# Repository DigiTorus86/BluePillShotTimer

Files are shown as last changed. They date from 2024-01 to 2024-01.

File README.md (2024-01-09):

# Blue Pill Shot Timer

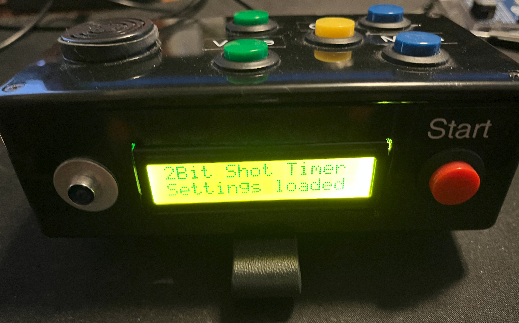
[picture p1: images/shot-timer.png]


The Blue Pill Shot Timer is a portable device for measuring the times between a start signal and a loud noise (typically a round going off in firearms training).  It also measures time intervals between successive shots in strings of fire.

Most settings can be customized and are saved to the STM32F103 EEPROM.

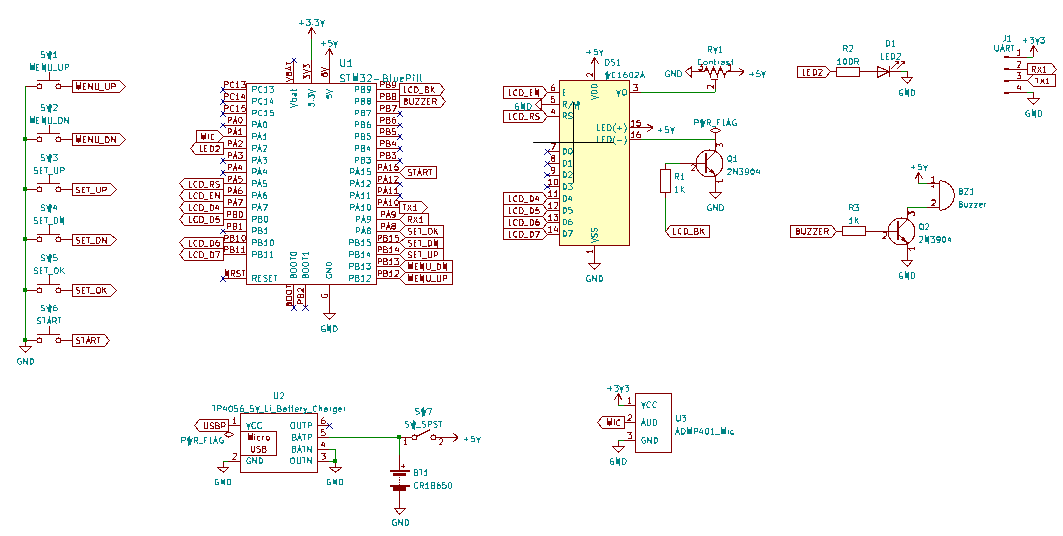
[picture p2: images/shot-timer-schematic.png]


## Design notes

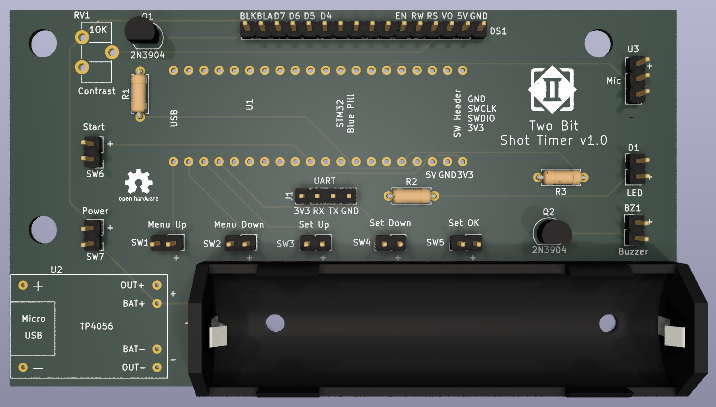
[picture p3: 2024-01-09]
images/shot-timer-pcb.png

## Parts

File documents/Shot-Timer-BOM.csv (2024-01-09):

Item | Qty | Reference(s) | Value | LibPart | Footprint | Datasheet | DNP
1 | 1 | BT1 | CR18650 | Device:Battery | Battery:BatteryHolder_MPD_BH-18650-PC2 | ~
2 | 1 | BZ1 | Buzzer | Device:Buzzer | Connector_PinHeader_2.54mm:PinHeader_1x02_P2.54mm_Vertical | ~
3 | 1 | D1 | LED2 | Device:LED | Connector_PinHeader_2.54mm:PinHeader_1x02_P2.54mm_Vertical | ~
4 | 1 | DS1 | WC1602A | Display_Character:WC1602A | Connector_PinHeader_2.54mm:PinHeader_1x16_P2.54mm_Vertical | http://www.wincomlcd.com/pdf/WC1602A-SFYLYHTC06.pdf
5 | 1 | J1 | UART | Connector:Conn_01x04_Male | Connector_PinHeader_2.54mm:PinHeader_1x04_P2.54mm_Vertical | ~
6 | 2 | Q1, Q2 | 2N3904 | Transistor_BJT:2N3904 | Package_TO_SOT_THT:TO-92_Inline | https://www.onsemi.com/pub/Collateral/2N3903-D.PDF
7 | 2 | R1, R3 | 1K | Device:R | Resistor_THT:R_Axial_DIN0207_L6.3mm_D2.5mm_P7.62mm_Horizontal | ~
8 | 1 | R2 | 100R | Device:R | Resistor_THT:R_Axial_DIN0207_L6.3mm_D2.5mm_P7.62mm_Horizontal | ~
9 | 1 | RV1 | Contrast | Device:R_Potentiometer_Trim_US | Potentiometer_THT:Potentiometer_ACP_CA9-H5_Horizontal | ~
10 | 1 | SW1 | MENU_UP | Switch:SW_Push | Connector_PinHeader_2.54mm:PinHeader_1x02_P2.54mm_Vertical | ~
11 | 1 | SW2 | MENU_DN | Switch:SW_Push | Connector_PinHeader_2.54mm:PinHeader_1x02_P2.54mm_Vertical | ~
12 | 1 | SW3 | SET_UP | Switch:SW_Push | Connector_PinHeader_2.54mm:PinHeader_1x02_P2.54mm_Vertical | ~
13 | 1 | SW4 | SET_DN | Switch:SW_Push | Connector_PinHeader_2.54mm:PinHeader_1x02_P2.54mm_Vertical | ~
14 | 1 | SW5 | SET_OK | Switch:SW_Push | Connector_PinHeader_2.54mm:PinHeader_1x02_P2.54mm_Vertical | ~
15 | 1 | SW6 | START | Switch:SW_Push | Connector_PinHeader_2.54mm:PinHeader_1x02_P2.54mm_Vertical | ~
16 | 1 | SW7 | SW_SPST | Switch:SW_SPST | Connector_PinHeader_2.54mm:PinHeader_1x02_P2.54mm_Vertical | ~
17 | 1 | U1 | STM32-BluePill | TwoBitSymbols:STM32-BluePill | TwoBitFootprints:STM32_BluePill | https://www.electronicshub.org/getting-started-with-stm32f103c8t6-blue-pill/
18 | 1 | U2 | TP4056_5V_Li_Battery_Charger | tp4056_5v_li_battery_charger:TP4056_5V_Li_Battery_Charger | TwoBitFootprints:TP4056_Li_Battery_Charger_Breakout
19 | 1 | U3 | ADMP401_Mic | TwoBitSymbols:ADMP401_Microphone_Breakout | Connector_PinHeader_2.54mm:PinHeader_1x03_P2.54mm_Vertical

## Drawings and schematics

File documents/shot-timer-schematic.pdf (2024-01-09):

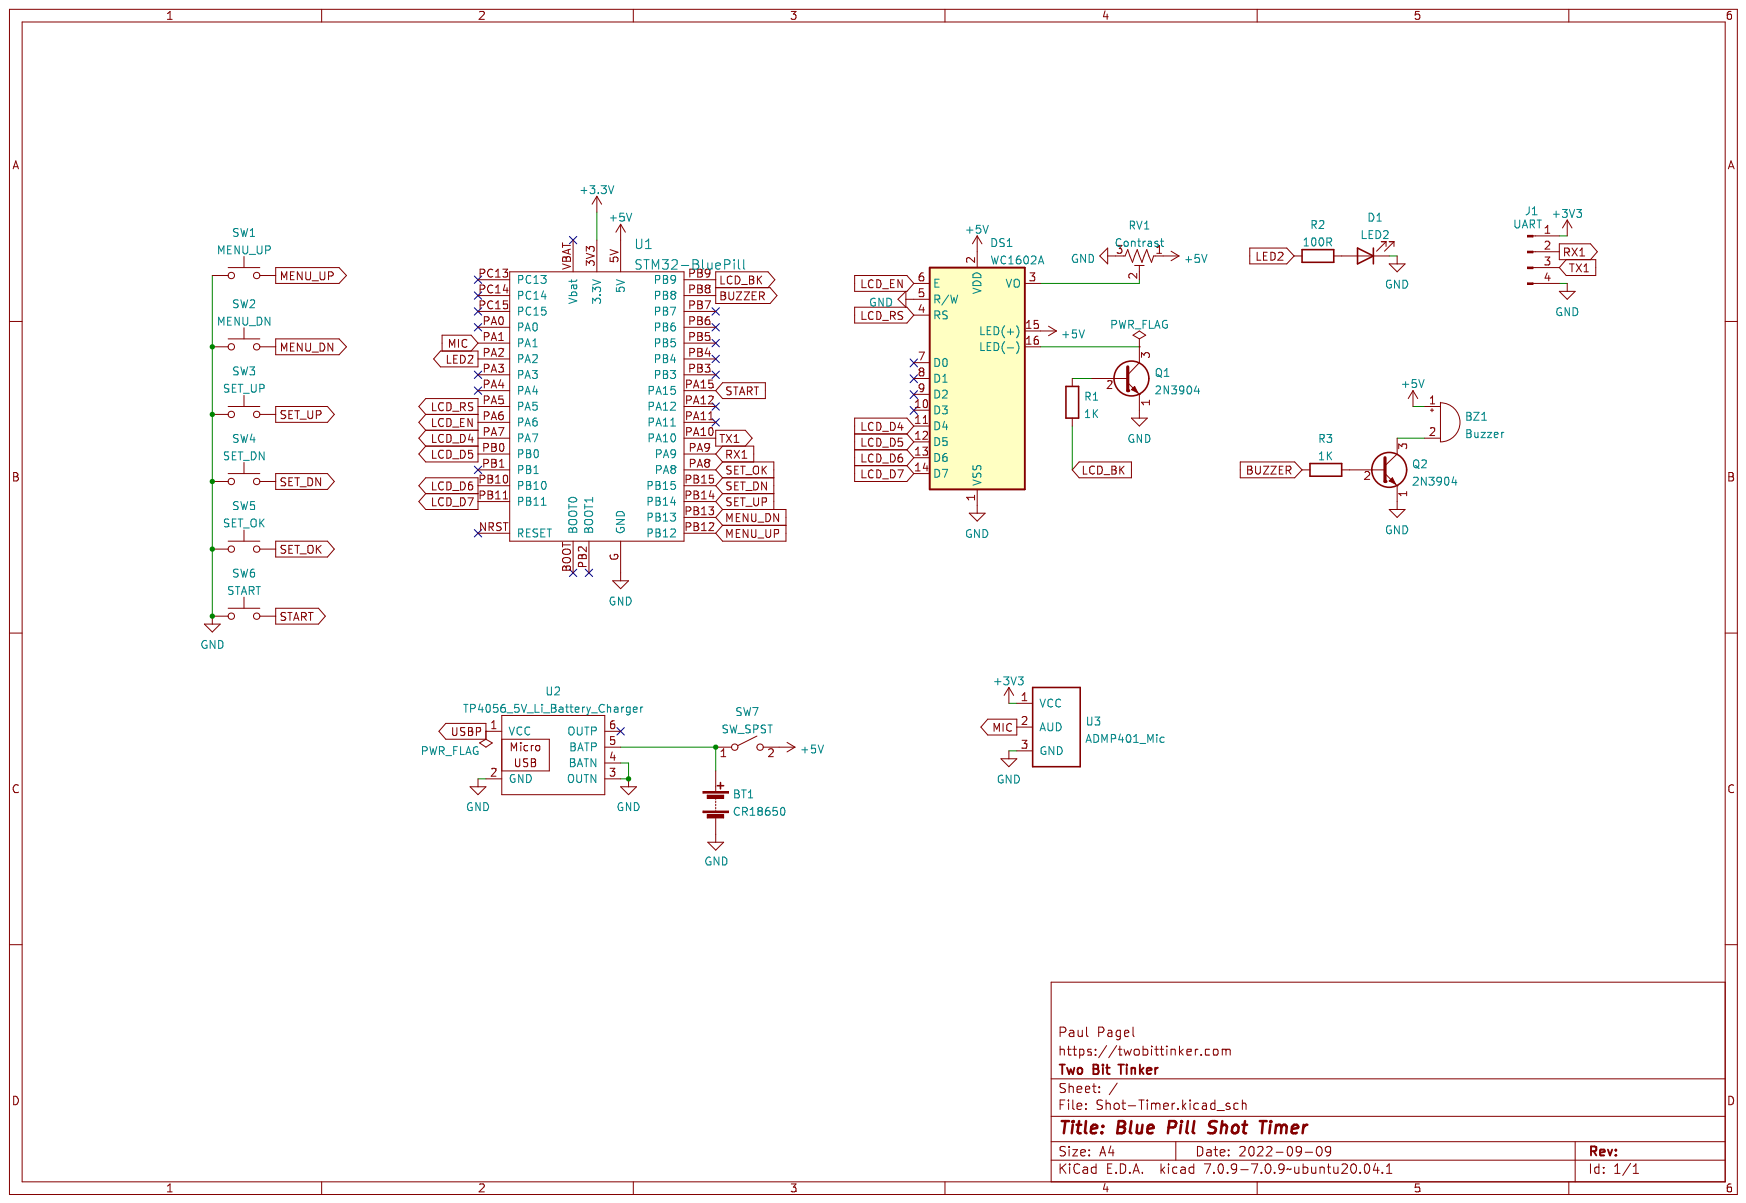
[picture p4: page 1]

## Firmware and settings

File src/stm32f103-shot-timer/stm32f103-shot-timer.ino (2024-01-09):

/* 2Bit Shot Timer
 *  
 * Configurable shot timer for detecting and recording shot times. 
 *  
 * Requires:
 * - STM32 BluePill (or similar microcontroller)
 * - 16x2 LCD character display
 * - ADMP401 Analog Microphone (or similar)
 * - Active Buzzer 3-24V
 * - 5 buttons
 * 
 * See BOM doc for full component list.
 * 
 * Uses the LiquidCrystal library for the HD44780-compatible LCD control:
 * https://github.com/arduino-libraries/LiquidCrystal
 * 
 * Uses the FlashStorage library by Khoi Hoang for storing user config settings in flash:
 * https://github.com/khoih-prog/FlashStorage_STM32F1
 *  
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
 * - 16x2 LCD Character Display Pins -
 * LCD 01 VSS pin to GND
 * LCD 02 VDD pin to 5V
 * LCD 03 VO pin to POT
 * LCD 04 RS pin to digital pin PB11
 * LCD 05 RW pin to GND
 * LCD 06 EN pin to digital pin PB10
 * LCD 07-10 D0 to D3 pins not used
 * LCD 11 D4 pin to digital pin PB0
 * LCD 12 D5 pin to digital pin PA7
 * LCD 13 D6 pin to digital pin PA6
 * LCD 14 D7 pin to digital pin PA5
 * LCD 15 BL+/BLA pin to 5V
 * LCD 16 BL-/BLK pin to GND
 */

#include <LiquidCrystal.h>
#include <FlashStorage_STM32F1.h>


#define FLASH_DEBUG                 2
#define USING_FLASH_SECTOR_NUMBER   (REGISTERED_NUMBER_FLASH_SECTORS - 2)

#define LCD_RS_PIN  PA5  //PB11
#define LCD_EN_PIN  PA6  //PB10
#define LCD_D4_PIN  PA7  //PB0
#define LCD_D5_PIN  PB0  //PA7
#define LCD_D6_PIN  PB10 //PA6
#define LCD_D7_PIN  PB11 //PA5
#define LCD_BK_PIN  PB9  // Backlight control connected to 2N3904 NPN base, connect BLK/- to emitter
#define MIC_PIN     PA1  // Analog in
#define BUZZER_PIN  PB8  // Buzzer control connected to 2N3904 NPN base, connect buzzer GND to emitter
#define MENU_UP_PIN PB12 // All button pins should be pulled up
#define MENU_DN_PIN PB13
#define SET_UP_PIN  PB14
#define SET_DN_PIN  PB15
#define SET_OK_PIN  PA8
#define START_PIN   PA15
#define LED1_PIN    PC13 // Built-in LED, in open-drain mode (LOW to turn on)
#define LED2_PIN    PA2  // Additional indicator LED

#define MAX_SHOTS   256
#define MAX_PARS    5
#define DC_OFFSET   2048   // DC offset in mic signal
#define NOISE       10     // Noise/hum/interference in mic signal

#define MIN_DETECT_THRESH 3000  // based on 12-bit ADC
#define MAX_DETECT_THRESH 4000

#define MIN_DEADTIME_SAMPLES 10
#define MAX_DEADTIME_SAMPLES 200


#define MIN_BUZZER_VOL 0        // PWM setting
#define MAX_BUZZER_VOL 250

#define MIN_BUZZER_MS 0
#define MAX_BUZZER_MS 1000

#define MIN_BKLIGHT_MS 0
#define MAX_BKLIGHT_MS 20000

#define EEPROM_VERSION 1
#define EEPROM_START   0xFEEDFACE
#define EEPROM_END     0xDEADBEEF

enum app_mode_type 
{
  MODE_TITLE,     // Display the app title
  MODE_MENU1,     // Start mode, delay times
  MODE_MENU2,     // Par times
  MODE_MENU3,     // Shot sensitivity
  MODE_MENU4,     // Buzzer volume and duration
  MODE_MENU5,     // Backlight duration + TBD
  MODE_STARTING,  // Countdown to start
  MODE_RECORDING, // Timer started, detecting and recording shots
  MODE_RESULTS,   // Display the recorded stats, split times
  MODE_REFRESH    // Set previous mode to refresh in order to trigger a redraw of the current screen
};

enum start_mode_type
{
  START_MODE_RANDOM,  // Use the a random delay between min and max value for the start countdown
  START_MODE_FIXED    // Use a specific countdown delay value (min_start_ms)
};

// ** Persisted configuration settings **

struct    app_config_type
{
  enum      start_mode_type start_mode; // Random or Fixed
  uint32_t  min_start_ms;
  uint32_t  max_start_ms; 
  uint16_t  par_count;
  long      par_ms[MAX_PARS];
  uint16_t  buzzer_vol;           // PWM setting for buzzer (0 = silent)
  uint32_t  buzzer_ms;            // Duration of buzzer sound
  uint32_t  bklight_ms;           // Backlight duration from when button last pushed to turnoff time
  int       detect_thresh;        // Shot detection threshold (using 12 bit ADC)
  long      min_interval_samples; // Minimum # of samples below detection threshold before next shot
};
app_config_type app_config;

// ** Operational values **
enum      app_mode_type app_mode, prev_app_mode;
long      start_time;             // All "time" values in reference to system clock millis()
long      end_time;
long      delay_end_time;
long      buzzer_off_time;
long      bklight_off_time;
long      par_time;
uint8_t   shot_count;
long      shot_time[MAX_SHOTS];
bool      buzzer_start_on;
bool      buzzer_par_on;

int       mic_lvl     = 10;       // Current "dampened" audio level
int       mic_min_avg = 0;        // For dynamic adjustment of graph low & high
int       mic_max_avg = 2048;

bool      btn_menu_up_pressed, btn_menu_up_released;
bool      btn_menu_dn_pressed, btn_menu_dn_released;
bool      btn_set_up_pressed, btn_set_up_released;
bool      btn_set_dn_pressed, btn_set_dn_released;
bool      btn_set_ok_pressed, btn_set_ok_released;
bool      btn_start_pressed, btn_start_released;


// The 16x2 LCD character display
LiquidCrystal lcd(LCD_RS_PIN, LCD_EN_PIN, LCD_D4_PIN, LCD_D5_PIN, LCD_D6_PIN, LCD_D7_PIN);

/*
 * Debug output for hex values
 */
void displayHex(uint16_t value)
{
  if (value <= 0xF)
    Serial.print("000");
  else if (value <= 0xFF)
    Serial.print("00");
  else if (value <= 0xFFF)
    Serial.print("0");
  Serial.print(value, HEX);
}

/*
 * Debug output for flash simulated EEPROM settings
 */
void displayEEPROM()
{
  uint8_t data;

  Serial.println("----Simulated EEPROM Dump----");
  lcd.clear();
  lcd.print("Dump:");
  
  for (int i = 0; i < 128; i++)
  {
    data = EEPROM.read(i);
    displayHex(data);
    Serial.print(" ");
    lcd.print(" ");
    lcd.print(data, HEX);

    if (i % 16 == 0)
    {
      delay(1000);
    }
    
  }
  Serial.println("");
  Serial.println("--------");
}

/*
 * Reads the app config settings from flash memory/simulated EEPROM if they are available.
 * Returns true if able to read settings.  False if no settings were read or failed validation.
 */
bool readConfig()
{
  int address = 0x0;
  int data;
  int data_version;
  
  Serial.print(F("\nStart EmulatedEEPROM on ")); Serial.println(BOARD_NAME);
  Serial.println(FLASH_STORAGE_STM32F1_VERSION);
  
  EEPROM.init();
     
  EEPROM.get(address, data);
  if (data != EEPROM_START)
  {
    Serial.print("Initial read value: ");
    displayHex(data);
    Serial.println();
    Serial.println(F("Unable to load settings from flash."));
    
    return false;
  }

  Serial.println(F("Getting settings from Simulated EEPROM"));

  // Future-proofing in case multiple firmware eeprom versions 
  address += sizeof(EEPROM_START);
  EEPROM.get(address, data_version);
  Serial.print(F("Data version: "));
  Serial.println(data_version);

  // -- read the actual config settings -- //

  address += sizeof(data_version);
  EEPROM.get(address, app_config);
  
  Serial.print(F("Start Mode: "));
  Serial.println(app_config.start_mode);
  Serial.print(F("Min Delay: "));
  Serial.println(app_config.min_start_ms);
  Serial.print(F("Max Delay: "));
  Serial.println(app_config.max_start_ms);

  Serial.print(F("Par Times: "));
  for (int i = 0; i < MAX_PARS; i++)
  {
    Serial.print(app_config.par_ms[i]);
  }

  Serial.println("");
  Serial.print(F("Buzzer ms: "));
  Serial.println(app_config.buzzer_ms);
  Serial.print(F("Backlight ms: "));
  Serial.println(app_config.bklight_ms);

  address += sizeof(app_config);
  EEPROM.get(address, data);
  if (data != EEPROM_END)
  {
    Serial.println(F("EEPROM write validation failed!"));
    Serial.print(F("Validation read value: "));
    displayHex(data);
    Serial.println();
    
    return false;
  }

  return true;
}

/*
 * Writes the app config settings to flash memory/simulated EEPROM
 * Returns true on success, false on failure.
 */
bool writeConfig()
{
  int address = 0x0;
  int data;

  data = EEPROM_START;
  EEPROM.put(address, data);

  data = EEPROM_VERSION;
  address += sizeof(EEPROM_START);
  EEPROM.put(address, data);

  address += sizeof(data);
  EEPROM.put(address, app_config);

  data = EEPROM_END;
  address += sizeof(app_config);
  EEPROM.put(address, data);

  EEPROM.commit();

  data = 0;
  EEPROM.get(address, data);
  
  return (data == EEPROM_END);
}

/*
 * Setup and Initialization 
 */
void setup() 
{
  Serial.begin(115200);
  while (!Serial);
  Serial.println("2Bit Shot Timer");
  
  // LEDs and display
  pinMode(LED1_PIN, OUTPUT);
  pinMode(LED2_PIN, OUTPUT);
  ledsOn();
  
  pinMode(LCD_BK_PIN, OUTPUT);
  digitalWrite(LCD_BK_PIN, HIGH); // turn on backlight
  
  lcd.begin(16, 2);
  lcd.setCursor(0, 0);
  lcd.print("2Bit Shot Timer");

  // Buttons 
  pinMode(MENU_UP_PIN, INPUT_PULLUP);
  pinMode(MENU_DN_PIN, INPUT_PULLUP);
  pinMode(SET_UP_PIN, INPUT_PULLUP);
  pinMode(SET_DN_PIN, INPUT_PULLUP);
  pinMode(SET_OK_PIN, INPUT_PULLUP);
  pinMode(START_PIN, INPUT_PULLUP);

  // Sound
  pinMode(MIC_PIN, INPUT_ANALOG);
  pinMode(BUZZER_PIN, OUTPUT);

  randomSeed(analogRead(MIC_PIN)); // for random start times

  if (readConfig())
  {
    lcd.setCursor(0, 1);
    lcd.print("Settings loaded");
  }
  else
  {
    // Unable to read from the simulated EEPROM or not previously set up
    // Use default configuration values instead

    lcd.setCursor(0, 1);
    lcd.print("Factory settings");
    
    app_config.start_mode = START_MODE_RANDOM;
    app_config.min_start_ms = 2000;
    app_config.max_start_ms = 5000;
    app_config.par_count = 1;

    for (int i = 0; i < MAX_PARS; i++)
    {
      app_config.par_ms[i] = 5000L;  
    }

    app_config.buzzer_vol = 75;
    app_config.buzzer_ms = 100;
    app_config.bklight_ms = 8000;
    app_config.detect_thresh = 3650;
    app_config.min_interval_samples = 50;

    if (!writeConfig())
    {
      lcd.setCursor(0, 1);
      lcd.print("EEPROM write err");
    }
  }
  
  bklight_off_time = millis() + app_config.bklight_ms;
  app_mode = MODE_TITLE;
  
  handleTitle();
  ledsOff();
}


void checkButtons()
{
  if (digitalRead(MENU_UP_PIN) == LOW)
  {
    btn_menu_up_pressed = true;
    bklight_off_time = millis() + app_config.bklight_ms;
  }
  else if(btn_menu_up_pressed)
  {
    btn_menu_up_pressed = false;
    btn_menu_up_released = true;
  }
  else
  {
    btn_menu_up_pressed = false;
    btn_menu_up_released = false;
  }

  if (digitalRead(MENU_DN_PIN) == LOW)
  {
    btn_menu_dn_pressed = true;
    bklight_off_time = millis() + app_config.bklight_ms;
  }
  else if(btn_menu_dn_pressed)
  {
    btn_menu_dn_pressed = false;
    btn_menu_dn_released = true;
  }
  else
  {
    btn_menu_dn_pressed = false;
    btn_menu_dn_released = false;
  }

  if (digitalRead(SET_UP_PIN) == LOW)
  {
    btn_set_up_pressed = true;
    bklight_off_time = millis() + app_config.bklight_ms;
  }
  else if(btn_set_up_pressed)
  {
    btn_set_up_pressed = false;
    btn_set_up_released = true;
  }
  else
  {
    btn_set_up_pressed = false;
    btn_set_up_released = false;
  }

  if (digitalRead(SET_DN_PIN) == LOW)
  {
    btn_set_dn_pressed = true;
    bklight_off_time = millis() + app_config.bklight_ms;
  }
  else if(btn_set_dn_pressed)
  {
    btn_set_dn_pressed = false;
    btn_set_dn_released = true;
  }
  else
  {
    btn_set_dn_pressed = false;
    btn_set_dn_released = false;
  }

  if (digitalRead(SET_OK_PIN) == LOW)
  {
    btn_set_ok_pressed = true;
    bklight_off_time = millis() + app_config.bklight_ms;
  }
  else if(btn_set_ok_pressed)
  {
    btn_set_ok_pressed = false;
    btn_set_ok_released = true;
  }
  else
  {
    btn_set_ok_pressed = false;
    btn_set_ok_released = false;
  }

  if (digitalRead(START_PIN) == LOW)
  {
    btn_start_pressed = true;
    bklight_off_time = millis() + app_config.bklight_ms;
  }
  else if(btn_start_pressed)
  {
    btn_start_pressed = false;
    btn_start_released = true;
  }
  else
  {
    btn_start_pressed = false;
    btn_start_released = false;
  }
}

/*
 * Turn all LEDs on
 */
void ledsOn()
{
  digitalWrite(LED1_PIN, LOW);
  digitalWrite(LED2_PIN, HIGH);
}

/*
 * Turn all LEDs off
 */
void ledsOff()
{
  digitalWrite(LED1_PIN, HIGH);
  digitalWrite(LED2_PIN, LOW);
}

/*
 * Turn the buzzer on
 */
void startBuzzer()
{
  ledsOn();
  
  pinMode(BUZZER_PIN, OUTPUT); // required when switching between digital and analog
  
  if (app_config.buzzer_vol == MAX_BUZZER_VOL)
  {
    digitalWrite(BUZZER_PIN, HIGH); // significantly louder than analog PWM
  }
  else
  {
    analogWrite(BUZZER_PIN, app_config.buzzer_vol);  
  }
  
  // digitalWrite(BUZZER_PIN, HIGH);
  digitalWrite(LCD_BK_PIN, LOW);
}

// Turn the buzzer off
void stopBuzzer()
{
  ledsOff();
  if (app_config.buzzer_vol == MAX_BUZZER_VOL)
  {
    digitalWrite(BUZZER_PIN, LOW);
  }
  else
  {
    analogWrite(BUZZER_PIN, 0);  
  }

  digitalWrite(LCD_BK_PIN, HIGH);
}


/*
 * Displays time to 2 decimal places, i.e. 9.87
 */
void printTime(long ms)
{
  char buff[10];
  float secs;

  secs = (float)ms / 1000.0f;
  sprintf(buff, "%d.%02d", (int)secs, (int)abs(secs*100)%100);
  lcd.print(buff);
}

/*
 * Displays time to 1 decimal place, i.e. 9.8
 */
void printSeconds(uint32_t ms)
{
  char buff[10];
  float secs;

  secs = (float)ms / 1000.0f;
  sprintf(buff, "%d.%01d", (int)secs, (int)abs(secs*10)%10);
  lcd.print(buff);
}

/*
 * Detects a gunshot or other loud noise that exceeds the analog detection threshold.
 */
void detectShot()
{
  static uint32_t samples_below_thresh;
  int             sample = 0;
  
  sample = analogRead(MIC_PIN);             // Raw reading from mic 
  sample = abs(sample - 2048 - DC_OFFSET);  // Center on zero
  sample = (sample <= NOISE) ? 0 : (sample - NOISE); // Remove noise/hum
  mic_lvl = ((mic_lvl * 7) + sample) >> 3;   // "Dampened" reading (else looks twitchy)

  lcd.setCursor(0,1);
  lcd.print(mic_lvl);
  lcd.print("  ");

  if ((mic_lvl > app_config.detect_thresh) && !buzzer_start_on && (samples_below_thresh > app_config.min_interval_samples))
  {
    shot_count += 1;
    shot_time[shot_count] = millis();
    end_time = millis();
    samples_below_thresh = 0;

    ledsOn();
    lcd.setCursor(7, 1);
    lcd.print(shot_count);
    ledsOff();
  }
  else
  {
    samples_below_thresh += 1;
  }
}

/*
 * Display the app title
 */
void handleTitle()
{
  if (prev_app_mode != MODE_TITLE)
  {
    prev_app_mode = MODE_TITLE;
    
    lcd.clear();
    lcd.setCursor(0, 0);
    lcd.print("2Bit Shot Timer");
  
    lcd.setCursor(0, 1);
    lcd.print("v1.0");
  }

  checkButtons();

  if (btn_menu_up_released)
  {
    app_mode = MODE_MENU1;
  }

  if (btn_menu_dn_released)
  {
    app_mode = MODE_MENU5;
  }

  if (btn_start_released)
  {
    app_mode = MODE_STARTING;
  }
}

/*
 * Menu1:  Start Mode (Delay, Fixed)  
 *         Min Delay
 *         Max Delay
 */
void handleMenu1()
{
  static uint8_t active_field;
  static uint8_t max_fields;
  
  if (prev_app_mode != MODE_MENU1)
  {
    prev_app_mode = MODE_MENU1;
    
    lcd.clear();
    lcd.setCursor(0, 0);
    lcd.print("Delay: ");
    if (app_config.start_mode == START_MODE_FIXED)
    {
      lcd.print("Fixed");
      
      lcd.setCursor(0, 1);
      lcd.print("Sec:");
      printSeconds(app_config.min_start_ms);
      
      max_fields = 2;
    }
    else
    {
      lcd.print("Random");
      
      lcd.setCursor(0, 1);
      lcd.print("Min:"); 
      printSeconds(app_config.min_start_ms);
      
      lcd.setCursor(8, 2);
      lcd.print("Max:");
      printSeconds(app_config.max_start_ms);
      
      max_fields = 3;
    }

    switch (active_field)
    {
      case 0: // start mode
        lcd.setCursor(7, 0);
        break;
      
      case 1: // min start delay ms
        lcd.setCursor(4, 1);
        break;

      case 2: // max start delay ms
        lcd.setCursor(12, 1);
        break;
    }

    lcd.cursor();
    lcd.blink();
  }

  checkButtons();

  if (btn_set_ok_released)
  {
    active_field = (active_field < max_fields - 1) ? active_field + 1 : 0;
    
    prev_app_mode = MODE_REFRESH;
    return;
  }

  if (btn_set_up_released)
  {
    switch (active_field)
    {
      case 0: // start mode
        app_config.start_mode = (start_mode_type)((app_config.start_mode + 1) % 2);
        break;
      
      case 1: // min start delay ms
        app_config.min_start_ms = (app_config.min_start_ms < 9900) ? app_config.min_start_ms + 100 : 9900;
        app_config.max_start_ms = (app_config.max_start_ms < app_config.min_start_ms) ? app_config.min_start_ms : app_config.max_start_ms;
        break;

      case 2: // max start delay ms
        app_config.max_start_ms = (app_config.max_start_ms < 9900) ? app_config.max_start_ms + 100 : 9900;
        break;
    }

    prev_app_mode = MODE_REFRESH;
    return;
  }

  if (btn_set_dn_released)
  {
    switch (active_field)
    {
      case 0: // start mode
        app_config.start_mode = (start_mode_type)((app_config.start_mode + 1) % 2);
        break;
      
      case 1: // min start delay ms
        app_config.min_start_ms = (app_config.min_start_ms > 100) ? app_config.min_start_ms - 100 : 100;
        break;

      case 2: // max start delay ms
        app_config.max_start_ms = (app_config.max_start_ms > 100) ? app_config.max_start_ms - 100 : 100;
        app_config.min_start_ms = (app_config.min_start_ms < app_config.max_start_ms) ? app_config.min_start_ms : app_config.max_start_ms;
        break;
    }
    
    prev_app_mode = MODE_REFRESH;
    return;
  }

  if (btn_menu_up_released)
  {
    app_mode = MODE_MENU2;
    return;
  }

  if (btn_menu_dn_released)
  {
    app_mode = MODE_RESULTS;
    writeConfig();
    return;
  }

  if (btn_start_released)
  {
    app_mode = MODE_STARTING;
  }
}

/*
 * Menu2: Par Times (count)
 *        Par Time Values (ms)
 */
void handleMenu2()
{
  static uint8_t active_field;
  static uint8_t active_par;
  
  if (prev_app_mode != MODE_MENU2)
  {
    prev_app_mode = MODE_MENU2;

    active_par = (active_field == 0) ? 0 : active_field - 1;
    
    lcd.clear();
    lcd.setCursor(0, 0);
    lcd.print("Par Times: ");
    lcd.print(app_config.par_count);
  
    lcd.setCursor(0, 1);
    lcd.print("#");
    lcd.print(active_par + 1);
    lcd.print(": ");
    printSeconds(app_config.par_ms[active_par]);

    switch (active_field)
    {
      case 0: // # of part times
        lcd.setCursor(11, 0);
        break;
      default: // par time ms
        lcd.setCursor(4, 1);
        break;
    }
    
    lcd.cursor();
    lcd.blink();
  }

  checkButtons();

  if (btn_set_ok_released)
  {
    // accept value and move to next field
    active_field = (active_field < 5) ? active_field + 1 : 0;
    
    prev_app_mode = MODE_REFRESH;
    return;
  }

  if (btn_set_up_released)
  {
    switch (active_field)
    {
      case 0: // # par times
        app_config.par_count = (app_config.par_count < MAX_PARS) ? app_config.par_count + 1 : MAX_PARS;
        break;
      default: // active par time ms
        app_config.par_ms[active_par] = (app_config.par_ms[active_par] < 9900) ? app_config.par_ms[active_par] + 100 : 9900;
        break;
    }
    
    prev_app_mode = MODE_REFRESH;
    return;
  }

  if (btn_set_dn_released)
  {
    switch (active_field)
    {
      case 0: // # par times
        app_config.par_count = (app_config.par_count > 0) ? app_config.par_count - 1 : 0;
        break;
      default: // active par time ms
        app_config.par_ms[active_par] = (app_config.par_ms[active_par] > 100) ? app_config.par_ms[active_par] - 100 : 100;
        break;
    }
    
    prev_app_mode = MODE_REFRESH;
    return;
  }

  if (btn_menu_up_released)
  {
    app_mode = MODE_MENU3;
    return;
  }

  if (btn_menu_dn_released)
  {
    app_mode = MODE_MENU1;
    return;
  }

  if (btn_start_released)
  {
    app_mode = MODE_STARTING;
  }
}
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
void loop() 
{
  switch (app_mode)
  {
    case MODE_TITLE:
      handleTitle();
      break;
    case MODE_MENU1:
      handleMenu1();
      break;
    case MODE_MENU2:
      handleMenu2();
      break;
    case MODE_MENU3:
      handleMenu3();
      break;
    case MODE_MENU4:
      handleMenu4();
      break; 
    case MODE_MENU5:
      handleMenu5();
      break; 
    case MODE_STARTING:
      handleStarting();
      break;
    case MODE_RECORDING:
      handleRecording();
      break;
    case MODE_RESULTS:
      handleResults();
      break;
  }

  // Common logic
  if (bklight_off_time > millis())
  {
    digitalWrite(LCD_BK_PIN, HIGH);
  }
  else
  {
    digitalWrite(LCD_BK_PIN, LOW);
  }

  if (btn_menu_up_pressed && btn_menu_dn_pressed)
  {
    lcd.clear();
    lcd.println("Saving settings");
    Serial.println("Saving config settings...");
    ledsOn();
    delay(app_config.buzzer_ms);
    ledsOff();
    
    if (!writeConfig())
    {
      lcd.println("Unable to save");
      Serial.println("Starting EEPROM Dump...");
    
      displayEEPROM();
    }
    
    prev_app_mode = MODE_REFRESH;
  }
}

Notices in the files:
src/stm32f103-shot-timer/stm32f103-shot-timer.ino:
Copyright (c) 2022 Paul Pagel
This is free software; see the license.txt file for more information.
